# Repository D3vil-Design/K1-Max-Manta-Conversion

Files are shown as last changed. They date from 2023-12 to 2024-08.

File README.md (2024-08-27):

# This project covers swapping a different mainboard into your K1 / K1Max 

Video of printer operating on M5P:

https://github.com/K1-Klipper/K1-Max-Manta-Conversion/assets/67915879/66ab00a4-9d4a-4fb8-99a1-330249be4a67

Find the community guide for K1Max here:
https://docs.google.com/document/d/1aXhsg2oq-k43R_2uWEkFxx4bUmE72XdTxru3hAUbRM0/edit

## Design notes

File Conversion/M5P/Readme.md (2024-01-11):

<center><H1> Required Items before starting:</h1></center> 

| Items: | Sites To Source from: |
| --- | --- |
| RS232 Adapter 2x | [AliExpress](https://www.aliexpress.us/item/2251832830864445.html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) \ [Amazon](https://www.amazon.com/dp/B0BL3NJTBJ?psc=1&ref=ppx_yo2ov_dt_b_product_details) \ [Amazon DE](https://www.amazon.de/dp/B0BCKBHQ8Y?psc=1&ref=ppx_yo2ov_dt_b_product_details) \ |
| Right Angle USB (See image) 2x of these | [Amazon USA](https://www.amazon.com/dp/B083TGBMR4?psc=1&ref=ppx_yo2ov_dt_b_product_details) |
| USB Breakout Board 1x (Optional) | [Amazon USA](https://www.amazon.com/dp/B09WYRNDDQ?ref=ppx_yo2ov_dt_b_product_details&th=1)|
| FTDI PH female adapter (optional) |[Amazon USA](https://www.amazon.com/dp/B0BPRQBTGY?psc=1&ref=ppx_yo2ov_dt_b_product_details)|
| FTDI XH female adapter (optional) |[Amazon USA](https://www.amazon.com/dp/B09DTL4T1W?psc=1&ref=ppx_yo2ov_dt_b_product_details)|
| Manta M5P + CB1 + 3x 2209  |[BigTreeTech](https://biqu.equipment/collections/control-board/products/manta-m4p-m8p?variant=40215553900642)|

## Preparation: 

Remove the bottom Metal cover from your K1 (this is the 4x rubber feet and 2x small silver m3 screws)
CAREFULLY  Remove the screws from the main board and unscrew the terminal plugs for the power/hotbed

Once you can move the mainboard away from the chassis slightly you can start removing the glue on all the plugs. I used a pair of sharp point tweezers to accomplish this job. You need to be very careful during this step 
Start undoing each connector on the Creality Mainboard VERY carefully making sure not to damage any connectors
Once you have all connectors and cables free from the Creality mainboard you can set this aside and start preparing your M5P

Should look something like this:
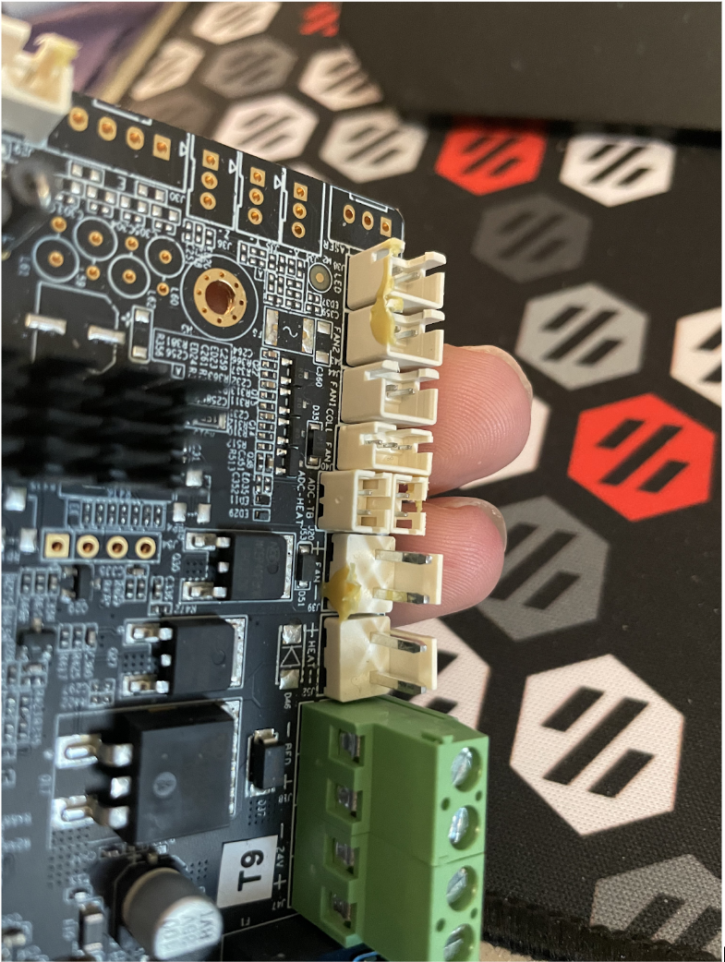
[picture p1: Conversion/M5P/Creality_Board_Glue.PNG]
Creality_Board


## M5P:

### Physical Setup of M5P:

Refer to the image below for jumpers that you need to install on the M5P:
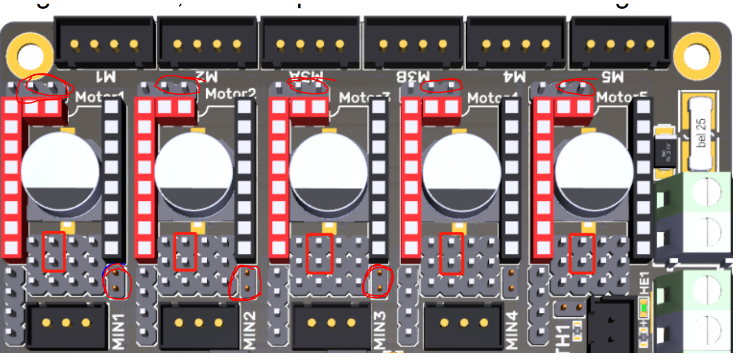
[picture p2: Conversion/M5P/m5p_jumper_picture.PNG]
M5P_Jumpers


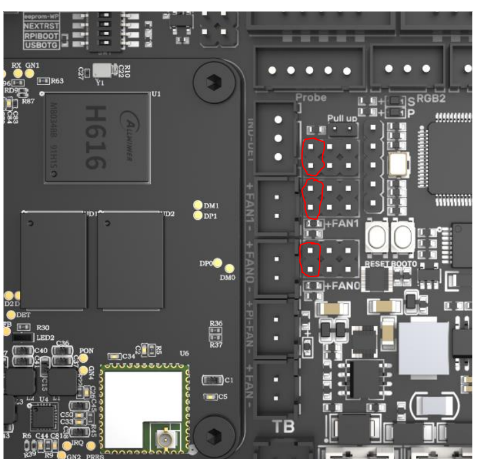
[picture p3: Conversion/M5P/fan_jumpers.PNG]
M5P_Fan_Jumpers


Once you have these jumpers installed you can proceed to screw the M5p into the printed adapter for your K1

When wiring the M5p the connections are as follows: 

Toolhead GND goes to the boards power input GND

Setting up the CB1:
Head over to : https://github.com/bigtreetech/CB1/releases
Download the CB1_Debian11_Klipper_kernel*.***.img.xz (Make sure it is not the one that says minimal)

Use an application such as balena etcher to write this to an SD card
Once this image is written do not forget to setup the system.cfg file to configure your wifi/timezone/klipperscreen rotation before the first bootup.

Insert the SD card into the receptacle on the M5P

Wiring The RS232 Adapters: 
|RS232: <-|->Toolhead PCB Cable:|
|---|---|
|TX |→ White|
|RX |→ Green|
|GND |→ Gnd (Take note this ground must be shared to the Ground for the power as well as to the RS232 dongle)|

|RS232: <-|->Bed PCB Cable:|
|---|---|
|RX |→ Green|
|TX |→ White|
|GND |→ Gnd (Take note this ground must be shared to the Ground for the power as well as to the RS232 dongle)|
|N/A | Yellow (ignore)|

The Rs232 adapters require a shared ground for the device they are talking to please make sure the grounds they share are appropriate (IE Bed cable ground should be shared at RGB1 header. Toolhead ground should be shared at board main ground) 

At this point you should be ready to boot up your M5P and let it load for the first time. After approx 5-10 min you should see the M5p on your wifi (as long as you did not forget to use the system.cfg before ejecting the SDCard) 

Once you can see this machine on your network you need to SSH into it in order to setup the klipper patches for K1 and flash the M5P with updated klipper.bin

Run this command in your SSH session:

wget https://github.com/sbtoonz/k1_klipper/raw/master/InstallKlipper.sh && sh InstallKlipper.sh

### Now you can proceed with flashing the M5P:
## Please follow these steps 

In your SSH Session 
```
cd ~/klipper
make menuconfig
```

Use the following options:
```
Enable Extra Low Level Options: X
STM32 architecture
STM32G0B1 SOC
8kib bootloader
8mhz crystal
USB On PA11/PA12
```

Press Q to exit the menu config and save the configuration

Then type:
```
make
```
And press enter.

Once this is complete run:
```
ls /dev/serial/by-id/*
```
Take note of the path it reports it should be something like:
```
/dev/serial/by-id/usb-123-port0
```

Then run:
```
sudo service klipper stop
make flash FLASH_DEVICE=/dev/serial/by-id/the-path-you-found-in-the-last-step
sudo service klipper start
```

Once you have completed these steps again run the Command :
```
ls /dev/serial/by-id/*
```

And take note of the path it returns (it can vary after flashing the firmware)

Use this path in your printer.cfg

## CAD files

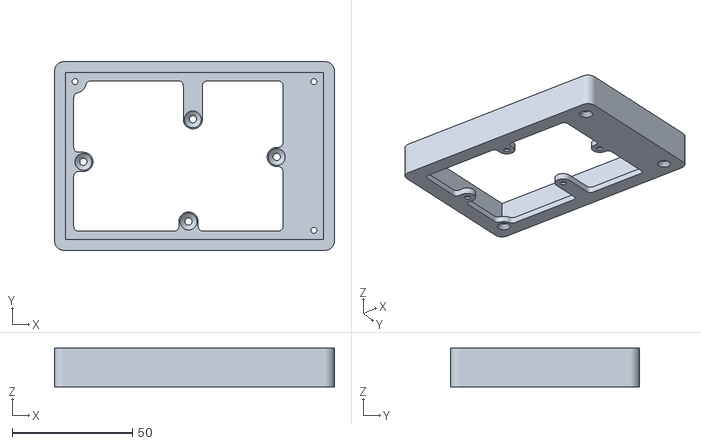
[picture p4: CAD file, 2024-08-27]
CommunityMods/K1_Screen_assembly_v4-screen.stl.stl
116.4 x 78.5 x 16.1

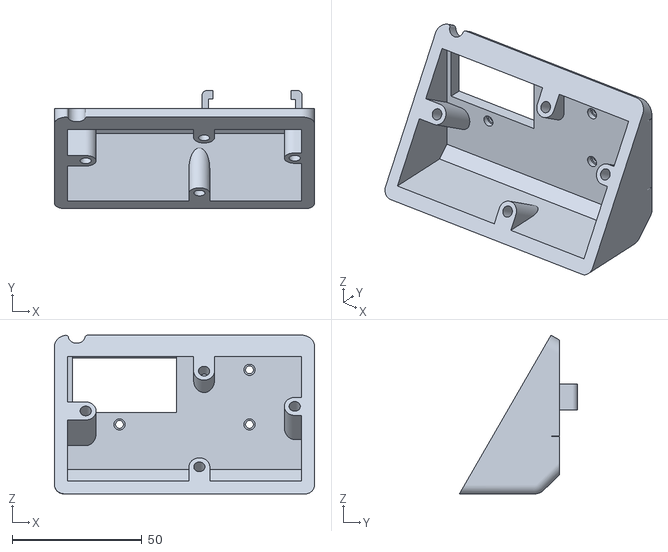
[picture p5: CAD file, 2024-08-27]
CommunityMods/K1_Screen_assembly_v4-holder.stl.stl
100.0 x 45.5 x 61.1

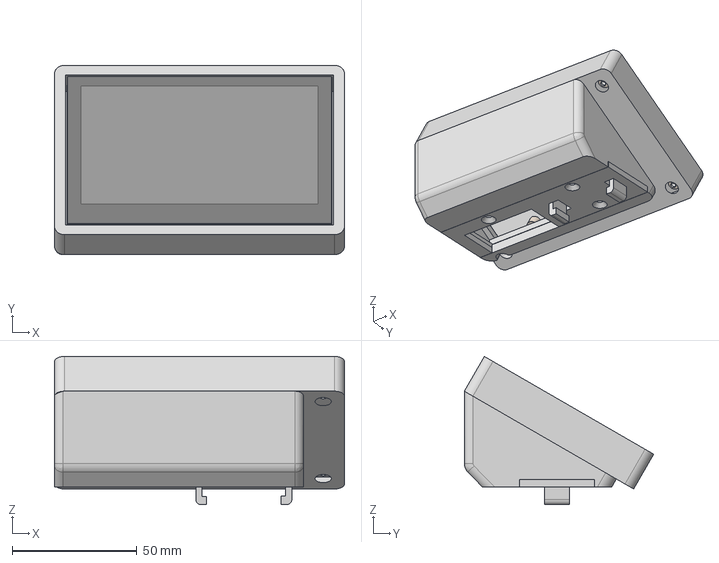
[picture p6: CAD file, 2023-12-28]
CommunityMods/K1_Screen_assembly_v4.step
116.4 x 76.0 x 59.4 mm
4.3in_800x480_DSI_LSD_Waveshare_RESTORED
K1 adapter

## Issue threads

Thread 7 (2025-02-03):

Manta M4P

siboj, 2025-02-03:
Hi,

Is it possible to only replace mainboard with manta m4p and re-use all other board that is on k1c printer?

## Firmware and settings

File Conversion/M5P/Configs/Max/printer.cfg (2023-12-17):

[include moonraker_obico_macros.cfg]
# K1 MAX
# Printer_size: 300x300x300
# Version: v1.0.2
# CreateDate: 2023/03/21
# Nozzle_mcu: chip: GD32F303CBT6
#             version: CR-K1-MAX-NOZZLE-V1.0.0
# Leveling_mcu: chip: GD32E230F8P6
#             version: CR-K1-MAX-LEVELING-V1.0.0
# mcu: chip: GD32F303RET6
#      version: CR4CU220812S12

[include sensorless.cfg]
[include gcode_macro.cfg]
[include timelapse.cfg]
[include KAMP_Settings.cfg]
[exclude_object]

[mcu]
serial: /dev/serial/by-id/usb-Klipper_stm32g0b1xx_56003A0016504D4D36343020-if00
restart_method: command

[mcu nozzle_mcu]
serial: /dev/serial/by-path/platform-5200000.usb-usb-0:1.2:1.0-port0 #bottom_port
baud: 230400
restart_method: command

[mcu leveling_mcu]
serial: /dev/serial/by-path/platform-5200000.usb-usb-0:1.3:1.0-port0 #top_port

baud: 230400
restart_method: command

[mcu CB1]
serial: /tmp/klipper_host_mcu

[temperature_sensor mcu_temp]
sensor_type: temperature_mcu
min_temp: 0
max_temp: 100

[temperature_sensor raspberry_pi]
sensor_type: temperature_host
min_temp: 10
max_temp: 100

[verify_heater extruder]
[verify_heater heater_bed]
check_gain_time: 120
heating_gain: 1.0
hysteresis: 10

[idle_timeout]
timeout: 99999999

[virtual_sdcard]
path: /home/biqu/printer_data/gcodes

[gcode_arcs]
resolution: 0.1

[stepper_x]
step_pin: PC8
dir_pin: PC9
enable_pin: !PA15
microsteps: 64
rotation_distance: 72
endstop_pin: tmc2209_stepper_x:virtual_endstop
position_endstop: 306.5
position_min: -2
position_max: 306.5
homing_speed: 36
homing_retract_dist:0

[tmc2209 stepper_x]
uart_pin:PD9
interpolate: True
run_current:1.2
hold_current:1.0
stealthchop_threshold: 0
diag_pin: PD3
driver_SGTHRS: 65
sense_resistor: 0.100

[stepper_y]
step_pin: PA10
dir_pin: PA14
enable_pin: !PA13
microsteps: 64
rotation_distance: 72
endstop_pin: tmc2209_stepper_y:virtual_endstop
position_endstop: -2
position_min: -2
position_max: 306
homing_speed: 36
homing_retract_dist:0

[tmc2209 stepper_y]
uart_pin:PD8
interpolate: True
run_current:1.2
hold_current:1.0
stealthchop_threshold: 0
diag_pin: ^PD2
driver_SGTHRS: 65
sense_resistor: 0.100

[stepper_z]
step_pin: PC6
dir_pin: PC7
enable_pin: !PA9
microsteps: 16
rotation_distance: 8
gear_ratio: 64:20
endstop_pin: tmc2209_stepper_z:virtual_endstop
#position_endstop: 0
position_max: 305
position_min: -10
homing_speed: 10
#custom
second_homing_speed: 1
homing_retract_dist: 2.0

[tmc2209 stepper_z]
uart_pin: PB10
run_current: 0.8
diag_pin: ^PC3
stealthchop_threshold: 0
driver_SGTHRS: 0
sense_resistor: 0.100

[extruder]
max_extrude_only_distance: 1000.0
max_extrude_cross_section: 80
step_pin: nozzle_mcu:PB1
dir_pin: nozzle_mcu:PB0
enable_pin: !nozzle_mcu:PB2
microsteps: 16
rotation_distance: 6.5
nozzle_diameter: 0.400
filament_diameter: 1.750
heater_pin: nozzle_mcu:PB7
sensor_type: EPCOS 100K B57560G104F
sensor_pin: nozzle_mcu:PA0
pressure_advance: 0.021
pressure_advance_smooth_time: 0.035
#control: pid
#pid_Kp: 25.013
#pid_Ki: 2.566
#pid_Kd: 60.966
min_temp: 0
max_temp: 320

[tmc2209 extruder]
uart_pin: nozzle_mcu:PB11
tx_pin: nozzle_mcu:PB10
uart_address: 3
run_current: 0.5
sense_resistor: 0.150
stealthchop_threshold: 0
# driver_IHOLDDELAY: 8
# driver_TPOWERDOWN: 20
# driver_TBL: 2
# driver_TOFF: 3
# driver_HEND: 0
# driver_HSTRT: 5

[firmware_retraction]
retract_length: 0.85
retract_speed: 35
unretract_extra_length: 0
unretract_speed: 35

[heater_bed]
heater_pin: PC13
sensor_type: EPCOS 100K B57560G104F
sensor_pin: PA0
#control: watermark
# control: pid
# pid_kp: 27
# pid_ki: 0.08
# pid_kd: 0
min_temp: -272
max_temp: 120

[filament_switch_sensor filament_sensor]
pause_on_runout: true
switch_pin: !PC2

[filament_switch_sensor filament_sensor_2]
pause_on_runout: true
switch_pin: !nozzle_mcu:PA10

[multi_pin heater_fans]
pins:nozzle_mcu:PB5,PB2

[heater_fan hotend_fan]
pin: multi_pin:heater_fans
heater: extruder
heater_temp: 40

[temperature_sensor chamber_temp]
sensor_type: EPCOS 100K B57560G104F
sensor_pin: PA1
min_temp: -170
max_temp: 270

[static_digital_output my_fan_output_pins]
pins: nozzle_mcu: PB6

[output_pin fan0]
pin: !nozzle_mcu: PB8
pwm: True
cycle_time: 0.0100
hardware_pwm: false
value: 0.00
scale: 255
shutdown_value: 0.0

[output_pin fan1]
pin: PA3
pwm: True
cycle_time: 0.0100
hardware_pwm: false
value: 0.00
scale: 255
shutdown_value: 0.0

[output_pin fan2]
pin: PA4
pwm: True
cycle_time: 0.0100
hardware_pwm: false
value: 0.00
scale: 255
shutdown_value: 0.0


[duplicate_pin_override]
pins: PA3, PA2, PA1

[temperature_fan chamber_fan]
pin: PA3
cycle_time: 0.0100
hardware_pwm: false
max_power: 1
shutdown_speed: 0
sensor_type: EPCOS 100K B57560G104F
sensor_pin: PA1
min_temp: 0
max_temp: 70
control: watermark
max_delta: 2
target_temp: 35.0
max_speed: 1.0
min_speed: 0.0

[output_pin LED]
pin: CB1:gpio79
pwm: false
#hardware_pwm: false
value: 1
#scale: 255
shutdown_value: 0.0

[output_pin power]
pin: !PC15
#pwm: false
#hardware_pwm: false
#value: 1
#scale: 255
#shutdown_value: 0

[adxl345]
cs_pin: nozzle_mcu:PA4
spi_speed: 5000000
axes_map: x,-z,y
spi_software_sclk_pin: nozzle_mcu:PA5
spi_software_mosi_pin: nozzle_mcu:PA7
spi_software_miso_pin: nozzle_mcu:PA6

[resonance_tester]
accel_chip: adxl345
accel_per_hz: 75
probe_points:
   110,110,10


[hx711s]
count: 4
use_mcu: leveling_mcu
sensor0_clk_pin: leveling_mcu:PA5
sensor1_clk_pin: leveling_mcu:PA2
sensor2_clk_pin: leveling_mcu:PA6
sensor3_clk_pin: leveling_mcu:PA7
sensor0_sdo_pin: leveling_mcu:PA1
sensor1_sdo_pin: leveling_mcu:PA0
sensor2_sdo_pin: leveling_mcu:PA3
sensor3_sdo_pin: leveling_mcu:PA4

[prtouch]
#z_offset: 0
max_press_cnt:5
base_count: 40
pi_count: 64
min_hold: 2000
max_hold: 60000
s_hot_min_temp: 160
s_hot_max_temp: 200
s_bed_max_temp: 60
pa_fil_len_mm: 5
pa_fil_dis_mm: 30
pa_clr_dis_mm: 30
bed_max_err: 4
max_dis_bef_g28: 0
dead_zone_bef_g28: 0
g28_sta0_speed: 2.5
g28_sta1_speed: 1.25
g29_rdy_speed: 1.5
g29_speed: 1.25
show_msg: false
g28_wait_cool_down: true
need_measure_gap: true
pa_clr_down_mm: -0.15
clr_noz_start_x: 130
clr_noz_start_y: 303
clr_noz_len_x: 40
clr_noz_len_y: 2
fix_z_offset:0.06
z_gap_00:0.03
z_gap_01:0.03
z_gap_10:-0.03
z_gap_11:-0.03
shake_cnt: 15
shake_max_velocity: 200
shake_max_accel: 500
gap_dis_range:0.4
#This is for the PRTouch self calibrate function.
extra_z_offset:-0.325


[filter]
hft_hz: 1
lft_k1: 0.3
lft_k1_oft: 0.95
lft_k1_cal: 0.95

[dirzctl]
use_mcu: mcu
step_base: 2

[bed_mesh]
speed: 500
mesh_min: 5,5
mesh_max: 200,200
probe_count: 6,6
fade_start: 3.0
fade_end: 10.0
algorithm: bicubic
bicubic_tension: 0.1

[display_status]

[printer]
kinematics: corexy
max_velocity: 800
max_accel: 20000
max_accel_to_decel: 20000
max_z_velocity: 20
square_corner_velocity: 5.0
max_z_accel: 300

[pause_resume]

[axis_twist_compensation]
speed: 300
horizontal_move_z: 5
calibrate_start_x: 20
calibrate_end_x: 200
calibrate_y: 112.5

#*# <---------------------- SAVE_CONFIG ---------------------->
#*# DO NOT EDIT THIS BLOCK OR BELOW. The contents are auto-generated.
#*#
#*# [prtouch default]
#*# z_gap_00 = 0.03
#*# z_gap_01 = 0.03
#*# z_gap_11 = -0.03
#*# z_gap_10 = -0.03
#*#
#*# [extruder]
#*# control = pid
#*# pid_kp = 23.139
#*# pid_ki = 1.953
#*# pid_kd = 68.550
#*#
#*# [heater_bed]
#*# control = pid
#*# pid_kp = 35.130
#*# pid_ki = 0.228
#*# pid_kd = 1355.582
#*#
#*# [bed_mesh default]
#*# version = 1
#*# points =
#*# 	0.037684, -0.023506, -0.065979, -0.076143
#*# 	0.000142, -0.039546, -0.076417, -0.099102
#*# 	-0.046450, -0.043116, -0.146911, -0.145859
#*# 	-0.098153, -0.068789, -0.163575, -0.163135
#*# 	-0.213890, -0.203886, -0.235232, -0.280176
#*# x_count = 4
#*# y_count = 5
#*# mesh_x_pps = 2
#*# mesh_y_pps = 2
#*# algo = lagrange
#*# tension = 0.1
#*# min_x = 92.61
#*# max_x = 199.98
#*# min_y = 81.3
#*# max_y = 199.98
#*#
#*# [input_shaper]
#*# shaper_type_x = zv
#*# shaper_freq_x = 51.6
#*# shaper_type_y = zv
#*# shaper_freq_y = 43.4
#*#
#*# [stepper_z]
#*# position_endstop = 0.020
#*#
#*# [prtouch]
#*# z_offset = 0.019

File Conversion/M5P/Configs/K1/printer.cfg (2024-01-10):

[include mainsail.cfg]
# K1
# Printer_size: 220x220x250
# Version: v1.0.2
# CreateDate: 2023/03/21
# Nozzle_mcu: chip: GD32F303CBT6
#             version: CR-K1-MAX-NOZZLE-V1.0.0
# Leveling_mcu: chip: GD32E230F8P6
#             version: CR-K1-MAX-LEVELING-V1.0.0
# mcu: chip: GD32F303RET6
#      version: CR4CU220812S12

[custom_macro] #??? in old printer_params.cfg
default_bed_temp: 50
default_extruder_temp: 240
g28_ext_temp: 140

[include sensorless.cfg]
[include gcode_macro.cfg]

[exclude_object]
#[display_status]
[respond]

[pause_resume]
recover_velocity: 100

[save_variables]
filename:/home/biqu/printer_data/config/variables.cfg


[virtual_sdcard]
path: /home/biqu/printer_data/gcodes

#Configure
#[firmware_retraction]
#retract_length: 0.85
#retract_speed: 35
#unretract_extra_length: 0
#unretract_speed: 35


[mcu]
serial: /dev/serial/by-id/usb-Klipper_stm32g0b1xx_420050000B504B5735313920-if00
restart_method: command

[mcu CB1] 
serial: /tmp/klipper_host_mcu

[mcu leveling_mcu]
serial: /dev/serial/by-path/platform-5200000.usb-usb-0:1.3:1.0-port0 #bottom_port
baud: 230400
restart_method: command

[mcu nozzle_mcu]
serial: /dev/serial/by-path/platform-5200000.usb-usb-0:1.2:1.0-port0 #top_port
baud: 230400
restart_method: command

[temperature_sensor mcu_temp]
sensor_type: temperature_mcu
min_temp: 0
max_temp: 100

[temperature_sensor raspberry_pi]
sensor_type: temperature_host
min_temp: 10
max_temp: 100

[verify_heater extruder]
[verify_heater heater_bed]
check_gain_time: 120
heating_gain: 1.0
hysteresis: 10

[idle_timeout]
timeout: 99999999

[gcode_arcs]
resolution: 0.1

[stepper_x]
step_pin: PC8
dir_pin: PC9
enable_pin: !PA15
rotation_distance: 72
endstop_pin: tmc2209_stepper_x:virtual_endstop
homing_speed: 36
homing_retract_dist:0
microsteps: 32
position_endstop: 229
position_min: -5
position_max: 229

[tmc2209 stepper_x]
uart_pin:PD9 
interpolate: True
hold_current:1.0
stealthchop_threshold: 0
diag_pin: PD3
driver_SGTHRS: 65
sense_resistor: 0.100
run_current:1.5

[stepper_y]
step_pin: PA10
dir_pin: PA14
enable_pin: !PA13
rotation_distance: 72
endstop_pin: tmc2209_stepper_y:virtual_endstop
homing_speed: 36
homing_retract_dist:0
position_endstop: -0.5
position_min: -0.5
position_max: 226
microsteps: 32

[tmc2209 stepper_y]
uart_pin:PD8
interpolate: True
hold_current:1.0
stealthchop_threshold: 0
diag_pin: ^PD2
driver_SGTHRS: 65
sense_resistor: 0.100
run_current:1.5

[stepper_z]
step_pin: PC6
dir_pin: PC7
enable_pin: !PA9
microsteps: 16
rotation_distance: 8
gear_ratio: 64:20
endstop_pin: tmc2209_stepper_z:virtual_endstop
second_homing_speed: 1 
homing_retract_dist: 2.0
position_endstop: 0
position_max: 255
position_min: -5

[tmc2209 stepper_z]
uart_pin: PB10
run_current: 0.8
diag_pin: ^PC3
stealthchop_threshold: 0
driver_SGTHRS: 0
sense_resistor: 0.100

[extruder]
max_extrude_only_distance: 1000.0
max_extrude_cross_section: 80
step_pin: nozzle_mcu:PB1
dir_pin: nozzle_mcu:PB0
enable_pin: !nozzle_mcu:PB2
microsteps: 16
nozzle_diameter: 0.400
filament_diameter: 1.750
heater_pin: nozzle_mcu:PB7
sensor_type: EPCOS 100K B57560G104F
sensor_pin: nozzle_mcu:PA0
pressure_advance_smooth_time: 0.02
rotation_distance: 6.693
control: pid
pid_Kp: 25.013
pid_Ki: 2.566
pid_Kd: 60.966
min_temp: 0
max_temp: 320

[tmc2209 extruder]
uart_pin: nozzle_mcu:PB11
tx_pin: nozzle_mcu:PB10
uart_address: 3
run_current: 0.45
sense_resistor: 0.150
stealthchop_threshold: 0
# driver_IHOLDDELAY: 8
# driver_TPOWERDOWN: 20
# driver_TBL: 2
# driver_TOFF: 3
# driver_HEND: 0
# driver_HSTRT: 5
#old cfg
run_current: 0.55

[heater_bed]
heater_pin: PA5 #??? Changed from PC13
sensor_type: EPCOS 100K B57560G104F
sensor_pin: PA0
control: pid
pid_kp: 27
pid_ki: 0.08
pid_kd: 0
min_temp: 0
max_temp: 120

[filament_switch_sensor filament_sensor]
pause_on_runout: true
switch_pin: !PC2
runout_gcode:
  {% if printer.extruder.can_extrude|lower == 'true' %}
    G91
    G0 E30 F600
    G90
  {% endif %}

[filament_switch_sensor filament_sensor_2]
pause_on_runout: true
switch_pin: !nozzle_mcu:PA10

[multi_pin heater_fans]
pins:nozzle_mcu:PB5,PB2

[heater_fan hotend_fan]
pin: multi_pin:heater_fans
heater: extruder
heater_temp: 40

[temperature_sensor chamber_temp]
sensor_type: EPCOS 100K B57560G104F
sensor_pin: PA2
min_temp: 0
max_temp: 125

[static_digital_output my_fan_output_pins]
pins: nozzle_mcu: PB6

[output_pin fan0]
#nozzle fan
pin: !nozzle_mcu: PB8
pwm: True
cycle_time: 0.0100
hardware_pwm: false 
value: 0.00
scale: 255
shutdown_value: 0.0

[output_pin fan1]
#rear fan
pin: PA3
pwm: True
cycle_time: 0.0100
hardware_pwm: false  
value: 0.00
scale: 255
shutdown_value: 0.0

[output_pin fan2]
#side fan
pin: PA4
pwm: True
cycle_time: 0.0100
hardware_pwm: false
value: 0.00
scale: 255
shutdown_value: 0.0

[duplicate_pin_override]
pins: PA3, PA2

[temperature_fan chamber_fan]
#rear fan
pin: PA3
cycle_time: 0.0100
hardware_pwm: false 
max_power: 1
shutdown_speed: 0
sensor_type: EPCOS 100K B57560G104F
sensor_pin: PA2
min_temp: 0
max_temp: 70
control: watermark
max_delta: 2
target_temp: 35.0
max_speed: 1.0
min_speed: 0.0

[led LED]
white_pin: CB1:gpio79
hardware_pwm: false
cycle_time: 0.01
initial_WHITE: 1.0

[adxl345]
cs_pin: nozzle_mcu:PA4
spi_speed: 5000000
axes_map: x,-z,y
spi_software_sclk_pin: nozzle_mcu:PA5
spi_software_mosi_pin: nozzle_mcu:PA7
spi_software_miso_pin: nozzle_mcu:PA6

[resonance_tester]
accel_chip: adxl345
accel_per_hz: 75
probe_points:
   110,110,10


[hx711s]
count: 4
use_mcu: leveling_mcu
sensor0_clk_pin: leveling_mcu:PA5
sensor1_clk_pin: leveling_mcu:PA2
sensor2_clk_pin: leveling_mcu:PA6
sensor3_clk_pin: leveling_mcu:PA7
sensor0_sdo_pin: leveling_mcu:PA1
sensor1_sdo_pin: leveling_mcu:PA0
sensor2_sdo_pin: leveling_mcu:PA3
sensor3_sdo_pin: leveling_mcu:PA4

[prtouch]
z_offset: 0
max_press_cnt:5
base_count: 40
pi_count: 64
min_hold: 2000
max_hold: 60000
s_hot_min_temp: 160
s_hot_max_temp: 200
s_bed_max_temp: 60
pa_fil_len_mm: 5
pa_fil_dis_mm: 30
pa_clr_dis_mm: 30
bed_max_err: 4
max_dis_bef_g28: 0
dead_zone_bef_g28: 0
g28_sta0_speed: 2.5
g28_sta1_speed: 1.25
g29_rdy_speed: 1.5
g29_speed: 1.25
show_msg: false
g28_wait_cool_down: true
need_measure_gap: true
pa_clr_down_mm: -0.15
clr_noz_start_x: 130
clr_noz_start_y: 220
clr_noz_len_x: 40
clr_noz_len_y: 2
fix_z_offset:0.06
z_gap_00:0.03
z_gap_01:0.03
z_gap_10:-0.03
z_gap_11:-0.03
shake_cnt: 15
shake_max_velocity: 200
shake_max_accel: 500
gap_dis_range:0.4

[filter]
hft_hz: 1
lft_k1: 0.3
lft_k1_oft: 0.95
lft_k1_cal: 0.95

[dirzctl]
use_mcu: mcu
step_base: 2

[bed_mesh]
zero_reference_position: 112,112
speed: 150
mesh_min: 5,5
mesh_max: 200,200
probe_count: 6,6
algorithm: bicubic
bicubic_tension: 0.1


[printer]
kinematics: corexy
max_velocity: 800
max_accel: 20000
max_accel_to_decel: 20000
max_z_velocity: 20
square_corner_velocity: 5.0
max_z_accel: 300


#*# <---------------------- SAVE_CONFIG ---------------------->
#*# DO NOT EDIT THIS BLOCK OR BELOW. The contents are auto-generated.
#*#
#*# [input_shaper]
#*# shaper_type_y = mzv
#*# shaper_freq_y = 56.6
#*# shaper_type_x = ei
#*# shaper_freq_x = 71.0
#*#
#*# [bed_mesh default]
#*# version = 1
#*# points =
#*# 	0.001365, 0.087156, 0.071062, 0.099094, 0.107687
#*# 	0.027364, 0.039563, 0.050375, 0.096031, 0.105594
#*# 	0.016146, 0.041250, 0.050000, 0.054844, 0.067656
#*# 	-0.009063, -0.004563, 0.059000, 0.044750, 0.057062
#*# 	-0.027875, 0.009312, 0.003000, 0.027312, 0.013656
#*# x_count = 5
#*# y_count = 5
#*# algo = lagrange
#*# mesh_x_pps = 2
#*# mesh_y_pps = 2
#*# tension = 0.1
#*# min_x = 48.0
#*# max_x = 172.0
#*# min_y = 63.0
#*# max_y = 157.0
#*#
#*# [bed_mesh good.25]
#*# version = 1
#*# points =
#*# 	0.168219, 0.195875, 0.208625, 0.248469, 0.281125, 0.343781, 0.393312
#*# 	0.161281, 0.149708, 0.209437, 0.250156, 0.254938, 0.274562, 0.321062
#*# 	0.146063, 0.176719, 0.193531, 0.222156, 0.233438, 0.240500, 0.278813
#*# 	0.177510, 0.216812, 0.222146, 0.241594, 0.229594, 0.245969, 0.266000
#*# 	0.208594, 0.203250, 0.231188, 0.233646, 0.223406, 0.231906, 0.260090
#*# 	0.261804, 0.247344, 0.250063, 0.232313, 0.233510, 0.258000, 0.260042
#*# 	0.326543, 0.319313, 0.306813, 0.310656, 0.317063, 0.303781, 0.336125
#*# min_x = 5.0
#*# max_x = 215.0
#*# min_y = 5.0
#*# max_y = 215.0
#*# x_count = 7
#*# y_count = 7
#*# mesh_x_pps = 2
#*# mesh_y_pps = 2
#*# algo = bicubic
#*# tension = 0.1

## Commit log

2023-12-17 add max config
    [printer.cfg]
2024-04-09 Created STL files of the parts
    [K1_Screen_assembly_v4-holder.stl.stl, K1_Screen_assembly_v4-screen.stl.stl]
